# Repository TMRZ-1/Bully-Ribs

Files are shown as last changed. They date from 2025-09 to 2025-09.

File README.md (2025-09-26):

# Bully-Ribs

Here you can find all the files for the Bully-Ribs project.

What could be improved:

- In KiCad I used the nice!nano controller, but I actually built it with a ProMicro RP2040, so the pin labels on the silkscreen are not correct :)))))))

- The PCB doesn’t have a reset button, but luckily the ProMicro RP2040 does.

- The case has the USB cutout a bit too high, so I just trimmed some plastic.






INSPIRATIONS

[Bully](https://github.com/zhol0777/bully-files)

[Lumberjack](https://github.com/peej/lumberjack-keyboard)

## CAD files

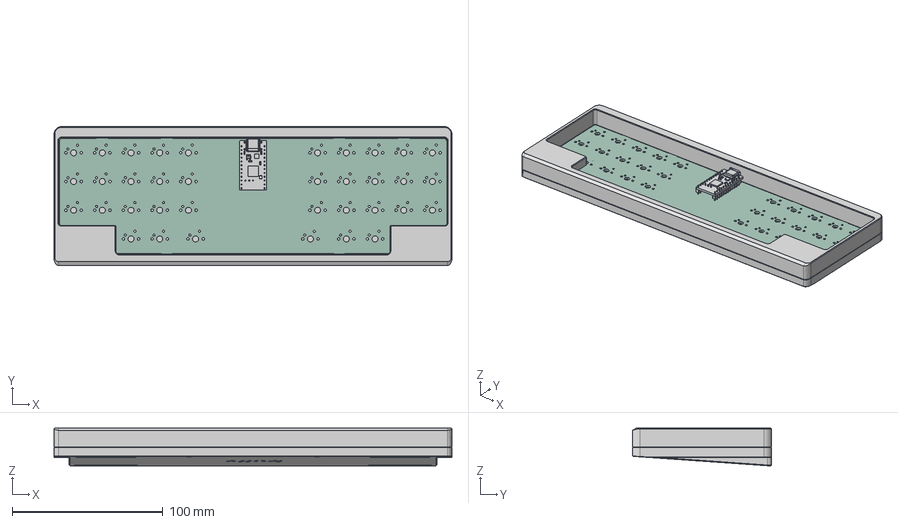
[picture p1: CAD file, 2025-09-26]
CASE/bullyribs.step
264.1 x 92.1 x 25.2 mm
Bottom
root
D_SOD_123 x 36
LeSTMovoz revision tomka_PCB
Top

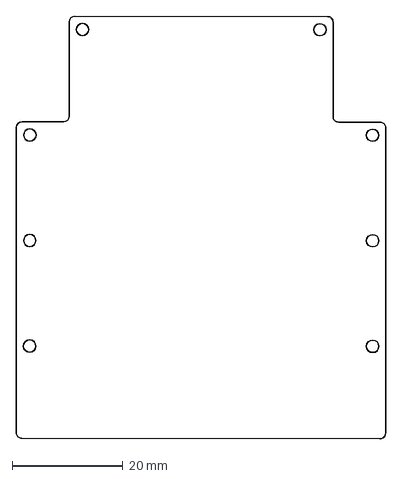
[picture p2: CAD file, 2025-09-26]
MIDDLE COVER/bullyribs.dxf
66.7 x 76.2 mm

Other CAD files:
CASE/bullyribs.f3d

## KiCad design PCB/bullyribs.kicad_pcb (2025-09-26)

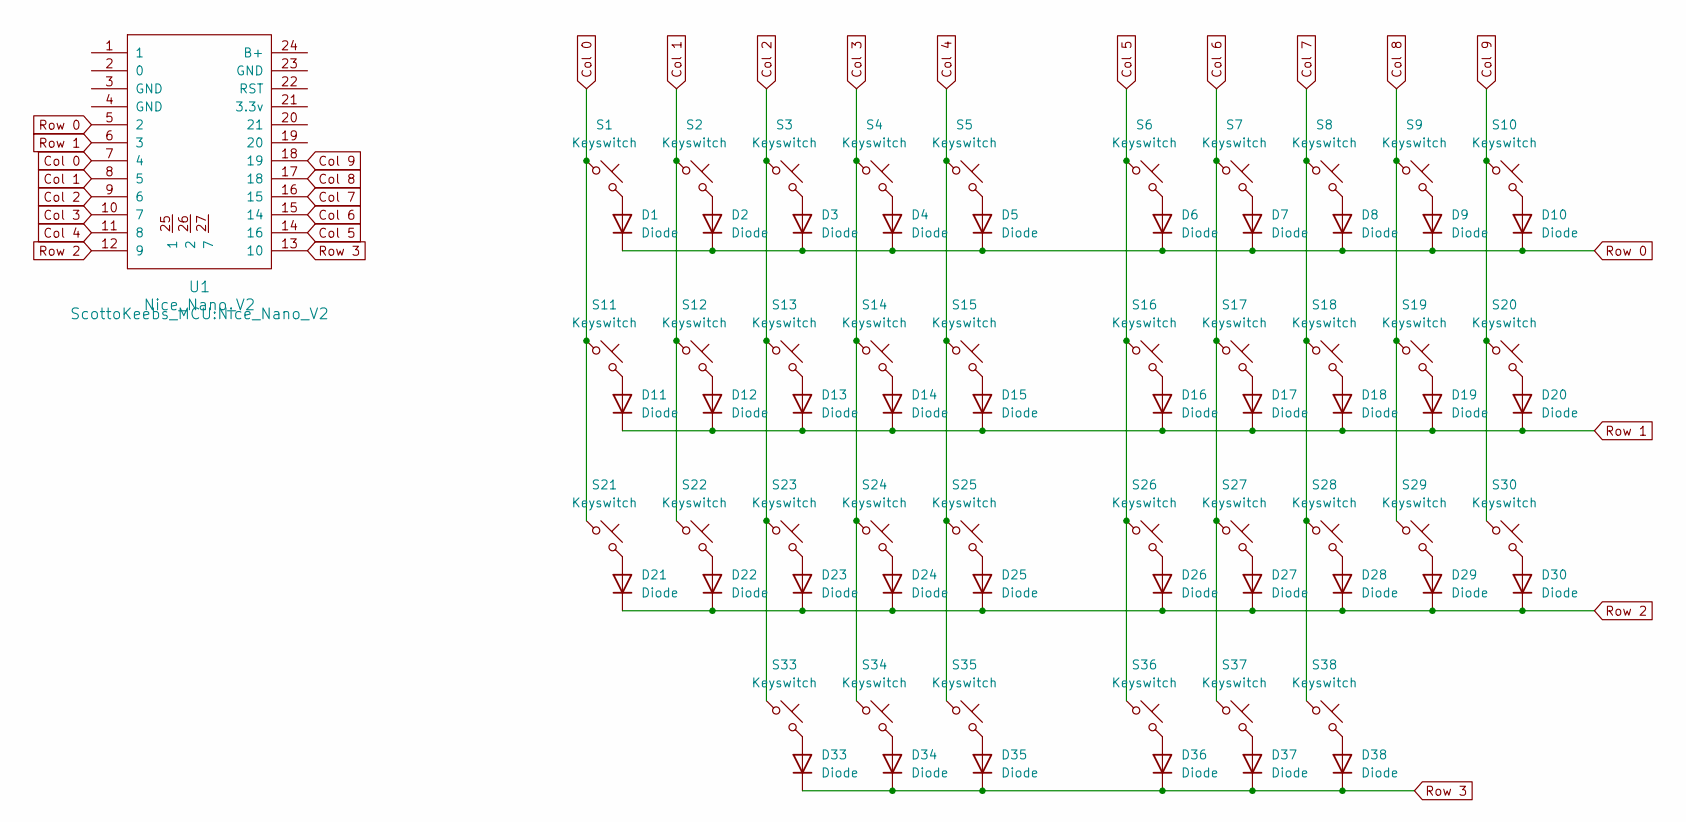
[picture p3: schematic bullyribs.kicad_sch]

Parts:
D1, D2, D3, D4, D5, D6, D7, D8, D9, D10, D11, D12, D13, D14, D15, D16, D17, D18, D19, D20, D21, D22, D23, D24, D25, D26, D27, D28, D29, D30, D33, D34, D35, D36, D37, D38: Diode; Diode_SOD-123
S1, S2, S3, S4, S5, S6, S7, S8, S9, S10, S11, S12, S13, S14, S15, S16, S17, S18, S19, S20, S21, S22, S23, S24, S25, S26, S27, S28, S29, S30, S33, S34, S37, S38: Keyswitch; MX_PCB_1.00u
S35, S36: Keyswitch; MX_PCB_1.50u
U1: Nice_Nano_V2

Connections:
Col 0: S1.1, S11.1, S21.1, U1.7 (4)
Col 1: S2.1, S12.1, S22.1, U1.8 (5)
Col 2: S3.1, S13.1, S23.1, S33.1, U1.9 (6)
Col 3: S4.1, S14.1, S24.1, S34.1, U1.10 (7)
Col 4: S5.1, S15.1, S25.1, S35.1, U1.11 (8)
Col 5: S6.1, S16.1, S26.1, S36.1, U1.14 (16)
Col 6: S7.1, S17.1, S27.1, S37.1, U1.15 (14)
Col 7: S8.1, S18.1, S28.1, S38.1, U1.16 (15)
Col 8: S9.1, S19.1, S29.1, U1.17 (18)
Col 9: S10.1, S20.1, S30.1, U1.18 (19)
unnamed: D1.2 (A), S1.2
unnamed: D2.2 (A), S2.2
unnamed: D3.2 (A), S3.2
unnamed: D4.2 (A), S4.2
unnamed: D5.2 (A), S5.2
unnamed: D6.2 (A), S6.2
unnamed: D7.2 (A), S7.2
unnamed: D8.2 (A), S8.2
unnamed: D9.2 (A), S9.2
unnamed: D10.2 (A), S10.2
unnamed: D11.2 (A), S11.2
unnamed: D12.2 (A), S12.2
unnamed: D13.2 (A), S13.2
unnamed: D14.2 (A), S14.2
unnamed: D15.2 (A), S15.2
unnamed: D16.2 (A), S16.2
unnamed: D17.2 (A), S17.2
unnamed: D18.2 (A), S18.2
unnamed: D19.2 (A), S19.2
unnamed: D20.2 (A), S20.2
unnamed: D21.2 (A), S21.2
unnamed: D22.2 (A), S22.2
unnamed: D23.2 (A), S23.2
unnamed: D24.2 (A), S24.2
unnamed: D25.2 (A), S25.2
unnamed: D26.2 (A), S26.2
unnamed: D27.2 (A), S27.2
unnamed: D28.2 (A), S28.2
unnamed: D29.2 (A), S29.2
unnamed: D30.2 (A), S30.2
unnamed: D33.2 (A), S33.2
unnamed: D34.2 (A), S34.2
unnamed: D35.2 (A), S35.2
unnamed: D36.2 (A), S36.2
unnamed: D37.2 (A), S37.2
unnamed: D38.2 (A), S38.2
Row 0: D1.1 (K), D2.1 (K), D3.1 (K), D4.1 (K), D5.1 (K), D6.1 (K), D7.1 (K), D8.1 (K), D9.1 (K), D10.1 (K), U1.5 (2)
Row 1: D11.1 (K), D12.1 (K), D13.1 (K), D14.1 (K), D15.1 (K), D16.1 (K), D17.1 (K), D18.1 (K), D19.1 (K), D20.1 (K), U1.6 (3)
Row 2: D21.1 (K), D22.1 (K), D23.1 (K), D24.1 (K), D25.1 (K), D26.1 (K), D27.1 (K), D28.1 (K), D29.1 (K), D30.1 (K), U1.12 (9)
Row 3: D33.1 (K), D34.1 (K), D35.1 (K), D36.1 (K), D37.1 (K), D38.1 (K), U1.13 (10)

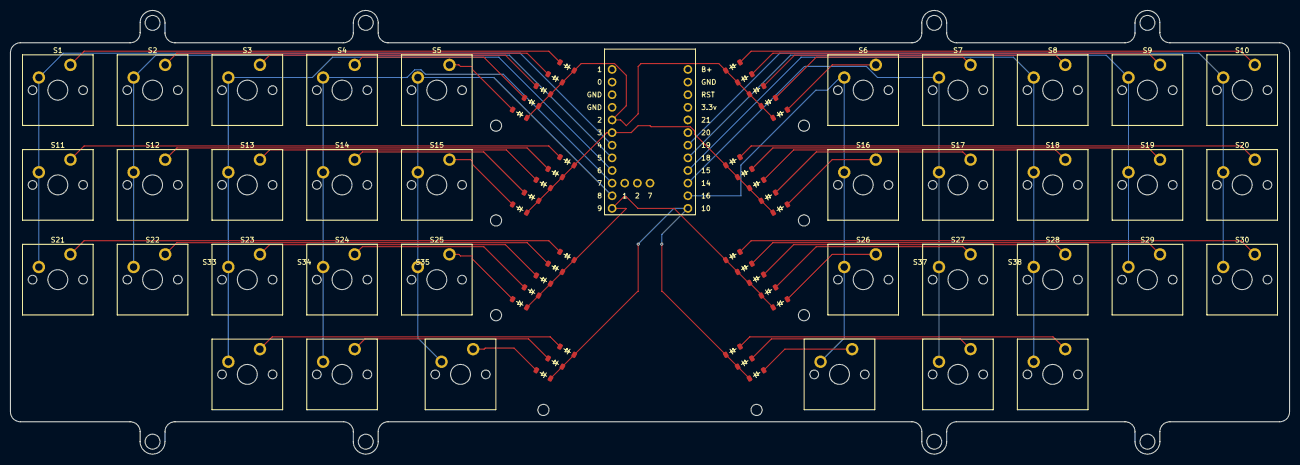
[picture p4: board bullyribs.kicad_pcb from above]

Board: 2 copper layers, 257.2 x 89.2 mm, 73 parts (0 on the bottom side), 50 nets.
